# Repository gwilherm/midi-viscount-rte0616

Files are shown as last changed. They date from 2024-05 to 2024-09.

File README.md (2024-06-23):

# MIDI Viscount RTE0616

MIDIfied Viscount 270 Pedalboard "RTE0616"

## Compile and flash

Compile using arduino-cli

```
cd firmware/firmware
make
make upload
```

## Unit tests

```
cd firmware
mkdir build; cd build
cmake ..
make
make test
```

## Configuration App

### Install dependencies

```
cd rte0616-config-app
npm install
```

### Web

```
cd rte0616-config-app
npm run build:web
npm run start:web
```

### Desktop (electron)

```
cd rte0616-config-app
npm run build:desktop
npm run start:desktop
```

# Schematics

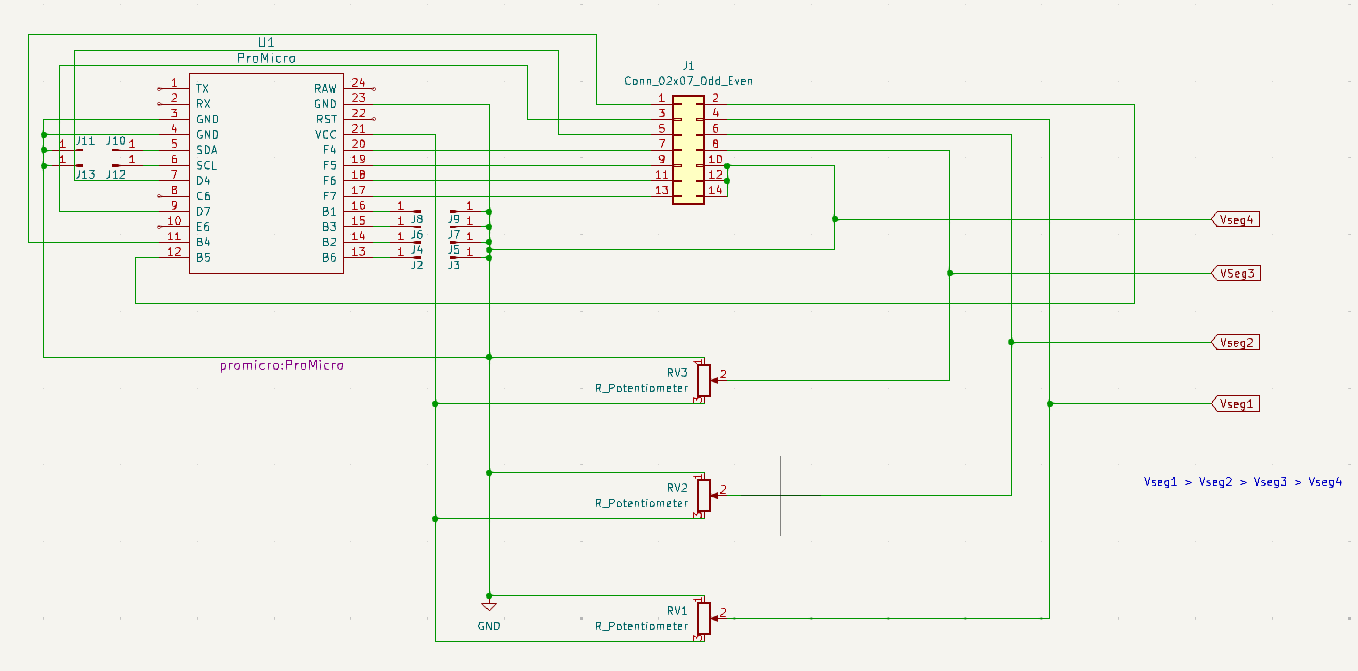
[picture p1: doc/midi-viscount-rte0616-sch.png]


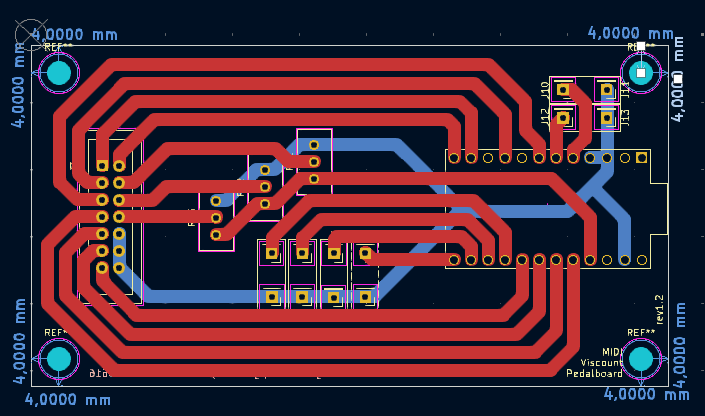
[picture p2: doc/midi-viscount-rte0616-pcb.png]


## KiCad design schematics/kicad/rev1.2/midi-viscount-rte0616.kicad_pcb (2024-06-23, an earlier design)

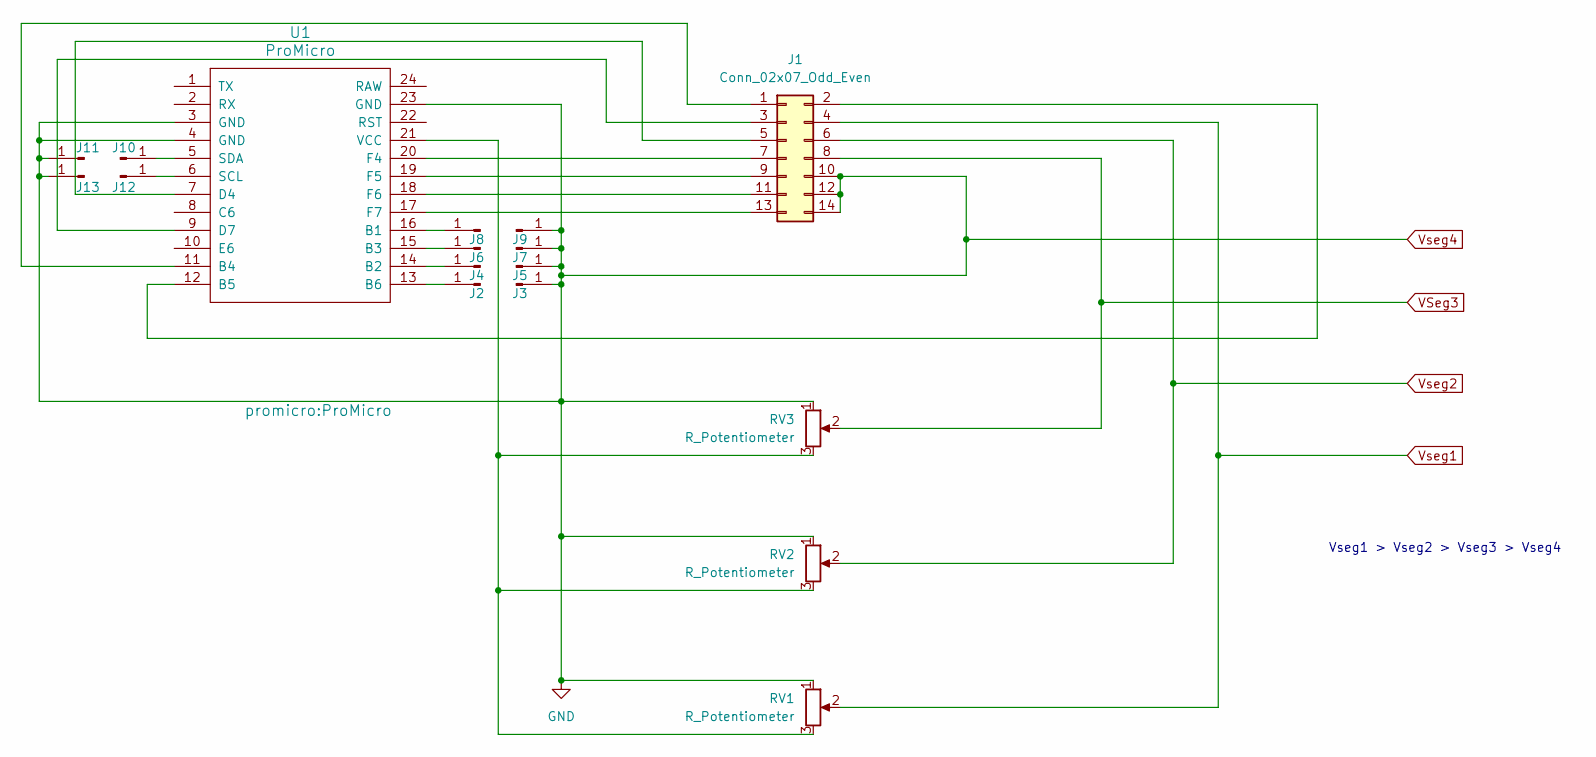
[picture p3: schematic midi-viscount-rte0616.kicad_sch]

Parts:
J1: Conn_02x07_Odd_Even; IDC-Header_2x07_P2.54mm_Vertical
J2, J3, J4, J5, J6, J7, J8, J9, J10, J11, J12, J13: Conn_01x01_Pin; PinHeader_1x01_P2.54mm_Vertical
RV1, RV2, RV3: R_Potentiometer; Potentiometer_Bourns_3296W_Vertical
U1: ProMicro

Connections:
unnamed: J1.1, U1.11 (B4)
unnamed: J1.2, U1.12 (B5)
unnamed: J1.3, U1.9 (D7)
unnamed: J1.5, U1.7 (D4)
unnamed: J1.7, U1.20 (F4)
unnamed: J1.9, U1.19 (F5)
unnamed: J1.11, U1.18 (F6)
unnamed: J1.13, U1.17 (F7)
unnamed: J2.1, U1.13 (B6)
unnamed: J4.1, U1.14 (B2)
unnamed: J6.1, U1.15 (B3)
unnamed: J8.1, U1.16 (B1)
unnamed: J10.1, U1.5 (SDA)
unnamed: J12.1, U1.6 (SCL)
unnamed: RV1.3, RV2.3, RV3.3, U1.21 (VCC)
VSeg3: J1.8, RV3.2
Vseg1: J1.4, RV1.2
Vseg2: J1.6, RV2.2
Vseg4: J1.10, J1.12, J1.14, J3.1, J5.1, J7.1, J9.1, J11.1, J13.1, RV1.1, RV2.1, RV3.1, U1.3 (GND), U1.4 (GND), U1.23 (GND)

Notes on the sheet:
Vseg1 > Vseg2 > Vseg3 > Vseg4

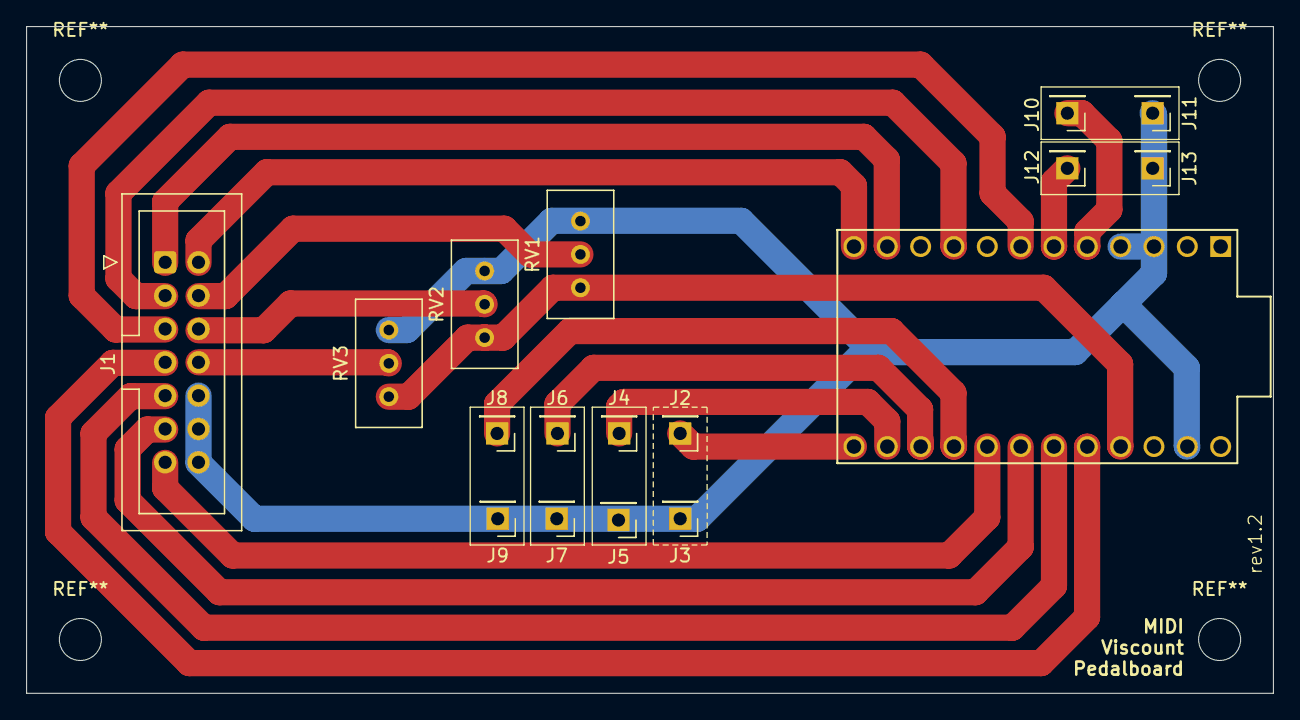
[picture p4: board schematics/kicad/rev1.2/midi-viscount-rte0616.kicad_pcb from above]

Board: 2 copper layers, 95.0 x 50.8 mm, 17 parts (0 on the bottom side), 19 nets.

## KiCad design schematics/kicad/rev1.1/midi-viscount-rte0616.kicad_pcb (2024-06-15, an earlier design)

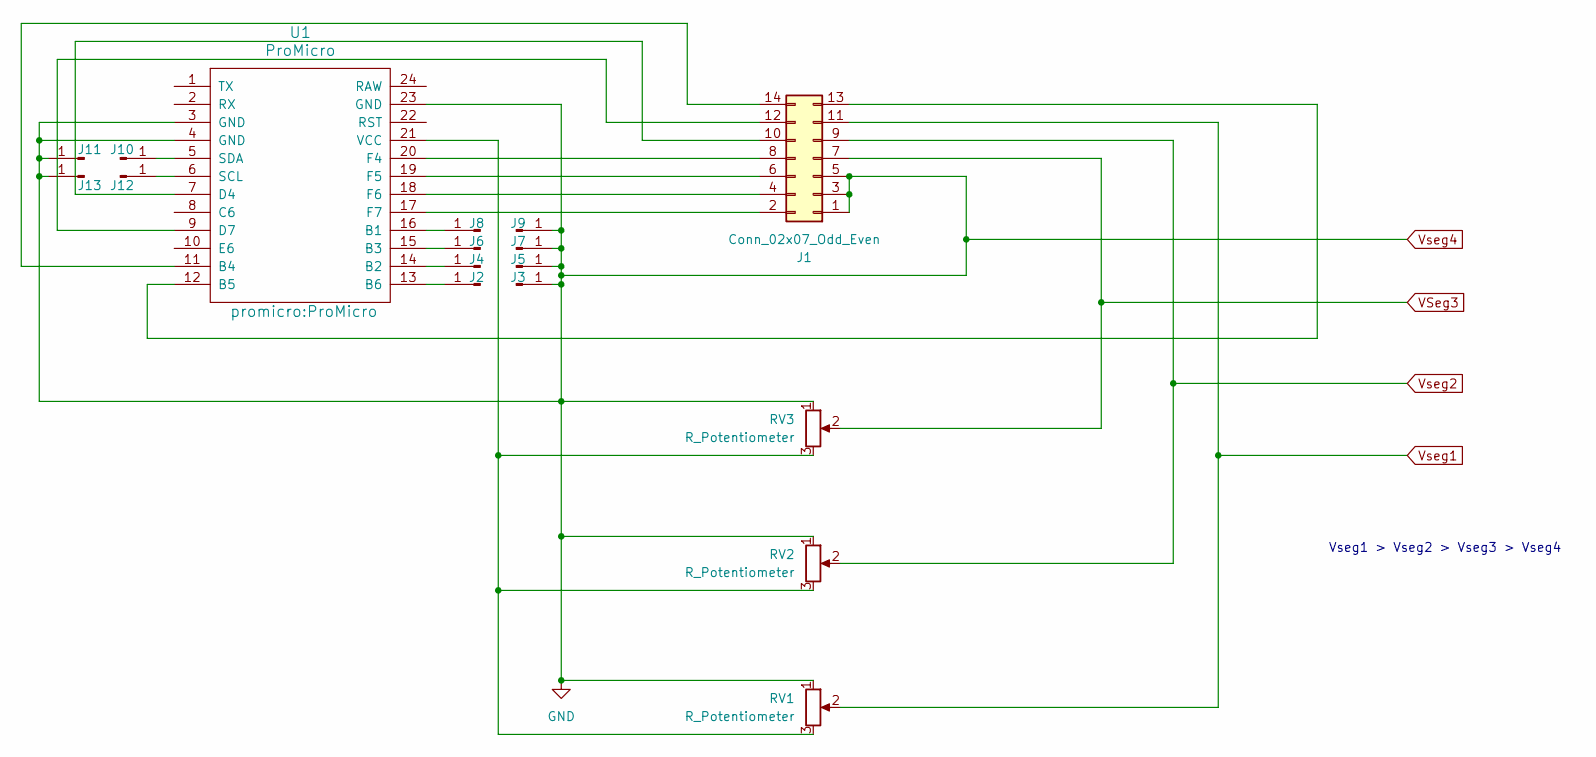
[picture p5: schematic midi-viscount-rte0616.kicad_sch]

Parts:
J1: Conn_02x07_Odd_Even; IDC-Header_2x07_P2.54mm_Vertical
J2, J3, J4, J5, J6, J7, J8, J9, J10, J11, J12, J13: Conn_01x01_Pin; PinHeader_1x01_P2.54mm_Vertical
RV1, RV2, RV3: R_Potentiometer; Potentiometer_Bourns_3266Y_Vertical
U1: ProMicro

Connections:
unnamed: J1.2, U1.17 (F7)
unnamed: J1.4, U1.18 (F6)
unnamed: J1.6, U1.19 (F5)
unnamed: J1.8, U1.20 (F4)
unnamed: J1.10, U1.7 (D4)
unnamed: J1.12, U1.9 (D7)
unnamed: J1.13, U1.12 (B5)
unnamed: J1.14, U1.11 (B4)
unnamed: J2.1, U1.13 (B6)
unnamed: J4.1, U1.14 (B2)
unnamed: J6.1, U1.15 (B3)
unnamed: J8.1, U1.16 (B1)
unnamed: J10.1, U1.5 (SDA)
unnamed: J12.1, U1.6 (SCL)
unnamed: RV1.3, RV2.3, RV3.3, U1.21 (VCC)
VSeg3: J1.7, RV3.2
Vseg1: J1.11, RV1.2
Vseg2: J1.9, RV2.2
Vseg4: J1.1, J1.3, J1.5, J3.1, J5.1, J7.1, J9.1, J11.1, J13.1, RV1.1, RV2.1, RV3.1, U1.3 (GND), U1.4 (GND), U1.23 (GND)

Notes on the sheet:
Vseg1 > Vseg2 > Vseg3 > Vseg4

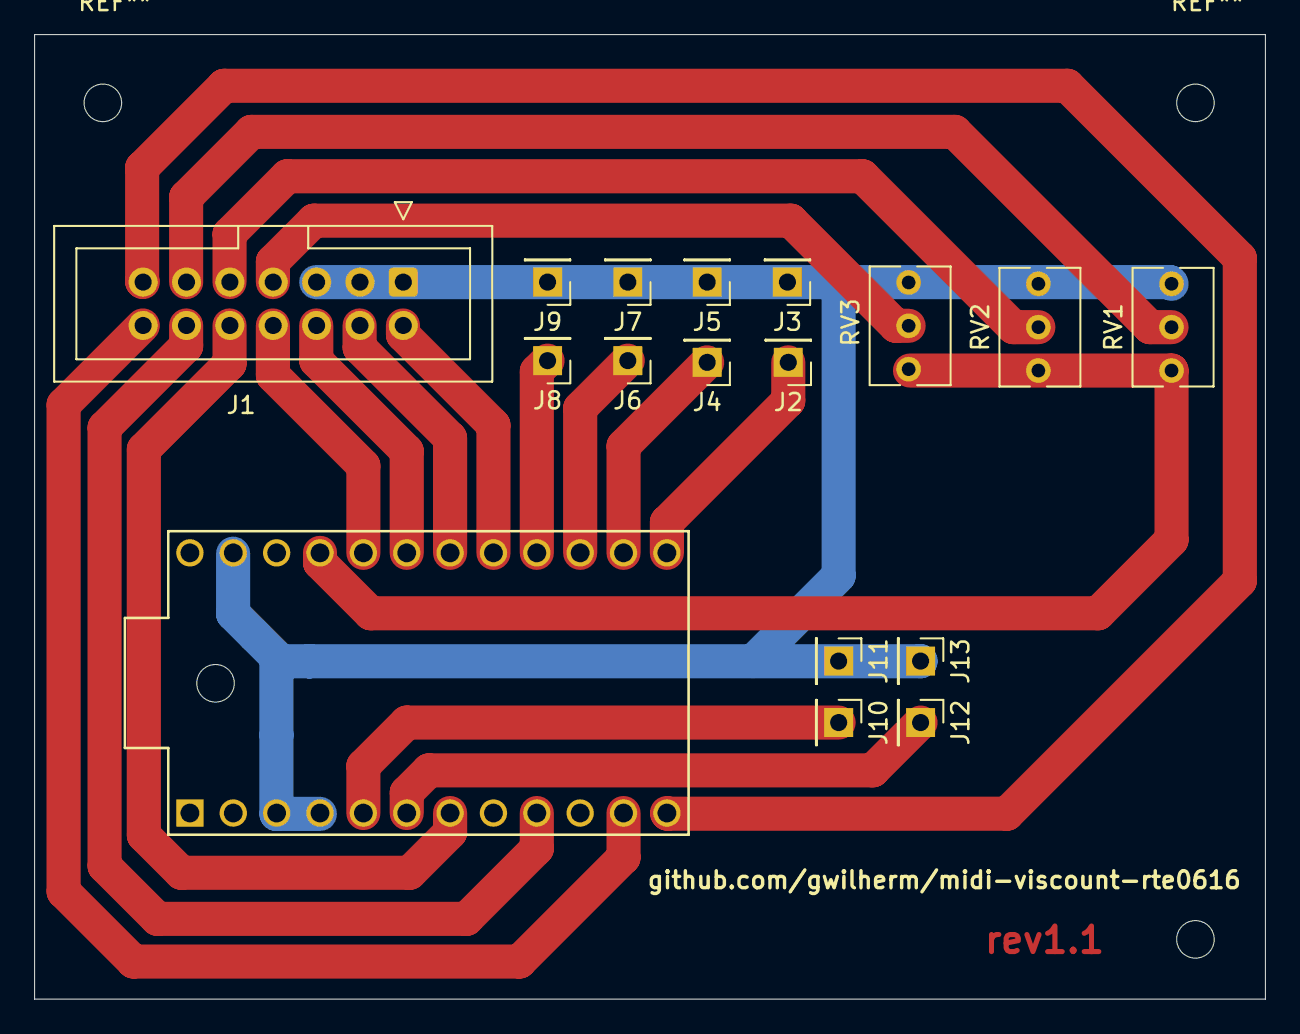
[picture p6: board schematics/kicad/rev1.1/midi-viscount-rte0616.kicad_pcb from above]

Board: 2 copper layers, 72.1 x 56.5 mm, 17 parts (0 on the bottom side), 19 nets.

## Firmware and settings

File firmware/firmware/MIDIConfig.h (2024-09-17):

#ifndef MIDI_CONFIG_H
#define MIDI_CONFIG_H

#define DEFAULT_MIDI_CHANNEL 1
#define DEFAULT_OCTAVE 3

#include <Arduino.h>

class MidiConfig
{
public:
    typedef enum {
        MONODIC_UP = 0,
        POLYPHONIC = 1,
        KEYBOARD_MODE_MAX = POLYPHONIC
    } keyboard_mode_t;

public:
    MidiConfig() : _channel(DEFAULT_MIDI_CHANNEL), _octave(DEFAULT_OCTAVE), _kbd_mode(MONODIC_UP) {};
    MidiConfig(uint8_t channel, uint8_t octave, keyboard_mode_t mode) : _channel(channel), _octave(octave), _kbd_mode(mode) {};
    virtual ~MidiConfig() = default;

    inline uint8_t getChannel() { return _channel; };
    inline void setChannel(uint8_t c) { _channel = c; };
    inline uint8_t getOctave() { return _octave; };
    inline void setOctave(uint8_t o) { _octave = o; };
    inline keyboard_mode_t getKeyboardMode() { return _kbd_mode; };
    inline void setKeyboardMode(keyboard_mode_t m) { _kbd_mode = m; };
    inline void reset();

private:
    uint8_t _channel;
    uint8_t _octave;
    keyboard_mode_t _kbd_mode;
};

void MidiConfig::reset()
{
    _channel = DEFAULT_MIDI_CHANNEL;
    _octave = DEFAULT_OCTAVE;
}

#endif

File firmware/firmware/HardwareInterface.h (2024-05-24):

#ifndef HARDWARE_INTERFACE_H
#define HARDWARE_INTERFACE_H

#include "IHardwareInterface.h"
#include "CalibrationConfig.h"
#include "pdlbrdkeys.h"

#include <Arduino.h>

class HardwareInterface : public IHardwareInterface {
public:
    HardwareInterface(CalibrationConfig& calibrationConfig);
    virtual ~HardwareInterface() = default;

    void setup();
    void loop();

    virtual int* getRawValues() { return &_rawValues[0]; };
    virtual int8_t* getSegmentedValues() { return &_pinSegment[0]; };

protected:
    void read();
    void process();
    bool approxEquals(int32_t ref, int32_t val);

protected:
    CalibrationConfig& _calibrationConfig;
    uint8_t _pin[NB_PIN] = {A0, A1, A2, A3, A6, A7, A8, A9};
    int8_t _pinSegment[NB_PIN] = {	PDLBRD_NO_SEG, PDLBRD_NO_SEG, PDLBRD_NO_SEG, PDLBRD_NO_SEG,
                                    PDLBRD_NO_SEG, PDLBRD_NO_SEG, PDLBRD_NO_SEG, PDLBRD_NO_SEG };
    int8_t _lastPinSegment[NB_PIN] = {	PDLBRD_NO_SEG, PDLBRD_NO_SEG, PDLBRD_NO_SEG, PDLBRD_NO_SEG,
                                        PDLBRD_NO_SEG, PDLBRD_NO_SEG, PDLBRD_NO_SEG, PDLBRD_NO_SEG };
    unsigned long _lastTick[NB_PIN] = {};
    int _rawValues[NB_PIN] = {0};
};

#endif

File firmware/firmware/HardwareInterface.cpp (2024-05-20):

#include "HardwareInterface.h"

HardwareInterface::HardwareInterface(CalibrationConfig& calibrationConfig):
	_calibrationConfig(calibrationConfig)
{}

void HardwareInterface::setup()
{
	for (int i = 0; i < NB_PIN; i++)
		pinMode(_pin[i], INPUT_PULLUP);
}

void HardwareInterface::loop()
{
	read();
	process();
}

void HardwareInterface::read()
{
	for (int i = 0; i < NB_PIN; i++)
	{
		_rawValues[i] = analogRead(_pin[i]);
#if defined (FW_DEBUG_VERBOSE_HWINT_READ)
		Serial.print(_rawValues[i]);
		Serial.print(" ");
	}
	Serial.println();
#else
	}
#endif
}

void HardwareInterface::process()
{
	int8_t newPinSegment[NB_PIN] = { 	PDLBRD_NO_SEG, PDLBRD_NO_SEG, PDLBRD_NO_SEG, PDLBRD_NO_SEG,
										PDLBRD_NO_SEG, PDLBRD_NO_SEG, PDLBRD_NO_SEG, PDLBRD_NO_SEG };
	for (uint8_t pin = 0; pin < NB_PIN; pin++)
	{
		for (uint8_t seg = PDLBRD_SEG_1; seg < PDLBRD_NB_SEG; seg++)
		{
			if (approxEquals(_calibrationConfig.getVSeg(seg), _rawValues[pin]))
			{
				newPinSegment[pin] = seg;
			}
		}

		if (newPinSegment[pin] != _lastPinSegment[pin])
			_lastTick[pin] = millis();

		if ((millis() - _lastTick[pin]) > 50)
		{
			if (_pinSegment[pin] != newPinSegment[pin])
				_pinSegment[pin] = newPinSegment[pin];
		}

#if defined (FW_DEBUG_VERBOSE_HWINT_PROCESS)
	    Serial.print(_pinSegment[pin]);
	    Serial.print(" ");
#endif
		_lastPinSegment[pin] = newPinSegment[pin];
	}
#if defined (FW_DEBUG_VERBOSE_HWINT_PROCESS)
	Serial.println();
#endif

}

bool HardwareInterface::approxEquals(int32_t ref, int32_t val)
{
	return ((val >= ref - _calibrationConfig.getMargin()) && (val <= ref + _calibrationConfig.getMargin()));
}

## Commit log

2024-04-28 Compile using arduino-cli
2024-05-07 ng add @angular/material
2024-05-07 Add device component
2024-05-07 Add identify and continue button
2024-05-07 Get calibration
2024-05-08 Limit CPU usage using throttleTime
2024-05-08 Send calibration
2024-05-21 Use potentiometers instead of resistors
    [midi-viscount-rte0616.kicad_pcb, midi-viscount-rte0616.kicad_sch]
2024-05-23 Add pin headers for pedals
    [midi-viscount-rte0616.kicad_pcb, midi-viscount-rte0616.kicad_sch]
2024-05-23 Update schematics
2024-05-31 Add device info marker to memory
2024-06-01 Use a struct for device info
2024-06-02 Config App: store config and calibration
2024-06-15 Schematics rev1.1
    [midi-viscount-rte0616.kicad_pcb, midi-viscount-rte0616.kicad_sch]
2024-06-15 Schematics rev1.2
    [midi-viscount-rte0616.kicad_pcb, midi-viscount-rte0616.kicad_sch]
2024-06-23 Quick fix for the inverted IDC header...
    [midi-viscount-rte0616.kicad_pcb, midi-viscount-rte0616.kicad_sch]
2024-06-23 Update docs
    Update docs
    [midi-viscount-rte0616.kicad_pcb, midi-viscount-rte0616.kicad_sch]
